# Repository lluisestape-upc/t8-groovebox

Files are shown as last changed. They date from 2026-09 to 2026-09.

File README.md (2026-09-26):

# T-8 Groovebox

A 16-step hardware groovebox built around an ESP32-WROOM-32, designed from scratch in KiCad 10. Two copper layers, 290 × 210 mm, DRC-clean and fabrication-ready.

> **Status: designed, not yet fabricated.**
> The layout passes DRC with **0 errors and 0 unconnected nets**, and the Gerber + drill package in [`fab/`](fab/) has been generated and checked. No board has been ordered yet, so nothing here has been measured on real hardware. Every performance figure in this README is a design intent, not a measurement.

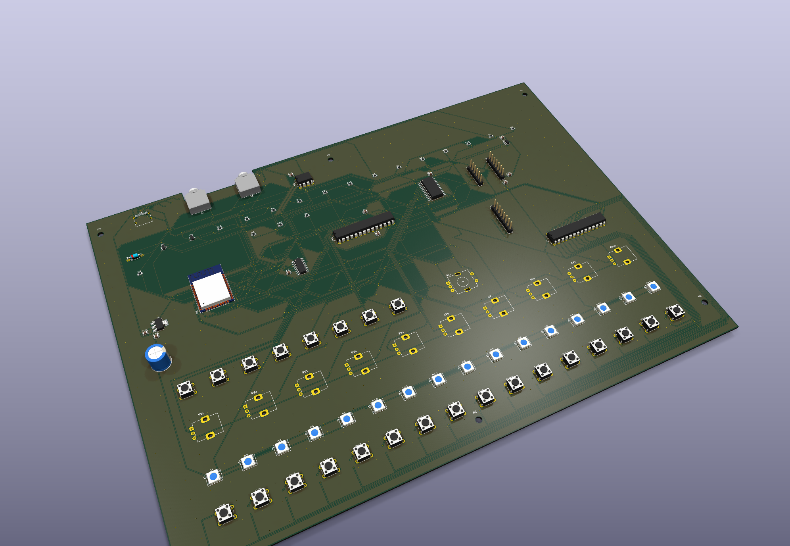
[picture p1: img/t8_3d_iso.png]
Isometric render of the assembled board


---

## What it is

A desktop groovebox in the spirit of the Roland T-8: sixteen step buttons with per-step RGB feedback, ten pots for live parameter control, a rotary encoder for menu navigation, a 2.4" colour display, MIDI in and out over TRS-A, and two independent audio outputs — a line-level I²S DAC and a class-D amplifier for a small onboard speaker. The whole thing is powered and programmed over a single USB-C connector.

The interesting part of this project is not the feature list, it is that the panel layout and most of the routing were **generated and repaired with the KiCad Python API** rather than drawn by hand. See [How the board was built](#how-the-board-was-built).

## Board at a glance

| | |
|---|---|
| Outline | 290.1 × 210.1 mm, with a 7 mm notch for the MIDI jacks |
| Copper layers | 2 (F.Cu / B.Cu), 1 oz |
| Footprints | 104 |
| Pads | 523 |
| Nets | 137 |
| Tracks | 2,570 segments |
| Vias | 1,148 (0.6 mm pad / 0.3 mm drill) |
| Copper zones | 1 GND plane, poured on both layers |
| Min track / clearance | 0.20 mm / 0.20 mm |
| Min drill | 0.30 mm |
| Min copper-to-edge | 0.50 mm |
| Mounting | 6 × M3 (3.2 mm) |
| DRC | 0 errors, 0 unconnected, 12 cosmetic silkscreen warnings |

### Renders

| Top | Bottom |
|---|---|
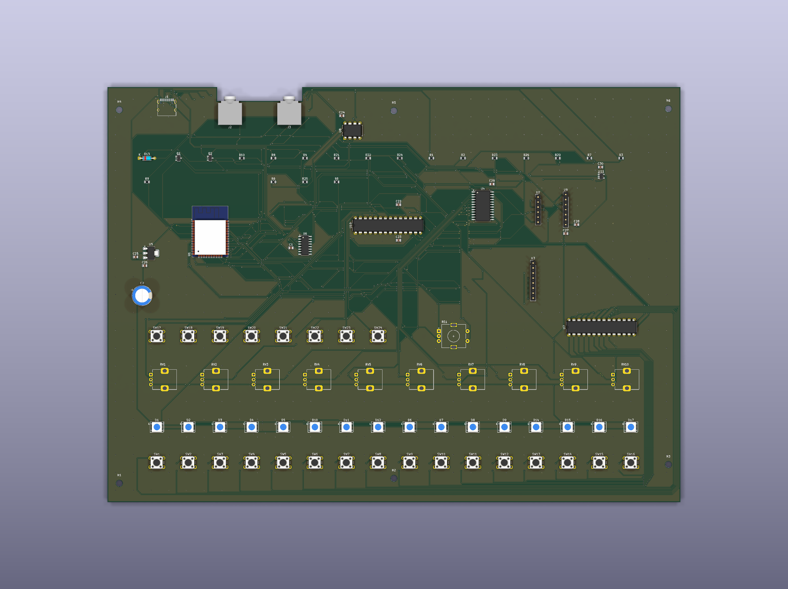
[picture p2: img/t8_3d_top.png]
Top
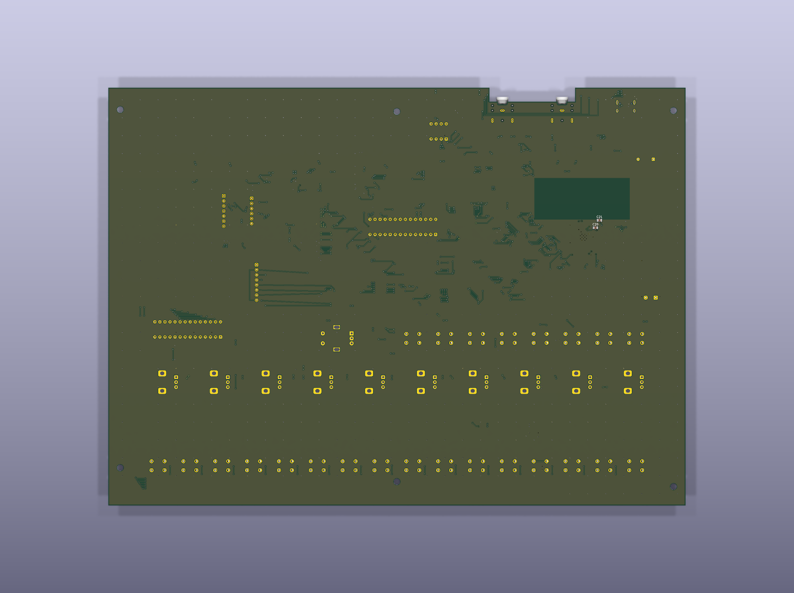
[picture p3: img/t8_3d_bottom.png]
Bottom
|  |  |

Vector fabrication views: [top](img/t8_2d_top.svg) · [bottom](img/t8_2d_bottom.svg)

PDFs: [schematic](T8Sequencer_esquematico.pdf) · [PCB](T8Sequencer_pcb.pdf)

---

## Signal chain

```mermaid
flowchart LR
  USB["USB-C J1"] --> UART["CH340C USB-UART"]
  USB --> LDO["AMS1117-3.3"]
  UART -->|UART0| ESP["ESP32-WROOM-32"]
  UART -.->|DTR / RTS via Q1, Q2| ESP
  LDO -->|3.3 V| ESP

  STEPS["16 step buttons"] --> EXP1["MCP23017 0x20"]
  FNKEYS["8 function buttons"] --> EXP2["MCP23017 0x21"]
  EXP1 -->|I2C| ESP
  EXP2 -->|I2C| ESP
  POTS["10 potentiometers"] --> MUX["CD74HC4067 16:1 mux"]
  MUX -->|ADC on GPIO34| ESP
  ENC["Rotary encoder + switch"] --> ESP

  ESP -->|GPIO16| LVL["74AHCT1G125 level shifter"]
  LVL -->|33 ohm series| LEDS["16x WS2812B"]
  ESP -->|SPI| DISP["ST7789 2.4in module"]
  ESP -->|I2S| DAC["I2S DAC header, line out"]
  ESP -->|I2S| AMP["MAX98357A module, speaker"]
  ESP -->|GPIO32| MOUT["MIDI OUT TRS-A, J3"]
  MIDIIN["MIDI IN TRS-A, J2"] --> OPTO["6N138 optocoupler"]
  OPTO -->|GPIO17| ESP
```

---

## Hardware

### Controls and indicators

| Qty | Part | Role |
|---|---|---|
| 16 | 6 mm tact switch | Step buttons (SW1–SW16) |
| 8 | 6 mm tact switch | PLAY, REC, SHIFT, PATT, TEMPO, CLEAR, F1, F2 (SW17–SW24) |
| 10 | Alps RK09K vertical | Parameter pots (RV1–RV10) |
| 1 | Alps EC11E + switch | Menu encoder |
| 16 | WS2812B (PLCC-4, 5×5 mm) | Per-step RGB feedback |
| 1 | ST7789 2.4" module | Display, on an 8-pin 2.54 mm header |

### Active devices

| Ref | Part | Package | Role |
|---|---|---|---|
| U1 | ESP32-WROOM-32 | module | Main MCU |
| U2 | — | 1×06 header | I²S DAC module, line out |
| U3 | ST7789 2.4" | 1×08 header | Display |
| U4 | CD74HC4067M | SOIC-24W | 16:1 analog mux for the pots |
| U5 | AMS1117-3.3 | SOT-223 | 3.3 V linear regulator |
| U6 | CH340C | SOIC-16 | USB to serial |
| U7 | MCP23017 | DIP-28 | I/O expander, step buttons (0x20) |
| U8 | 6N138 | DIP-8 | MIDI IN isolation |
| U9 | MAX98357A | 1×07 header | Class-D amp module, speaker out |
| U10 | MCP23017 | DIP-28 | I/O expander, function buttons (0x21) |
| U11 | 74AHCT1G125 | SOT-23-5 | 3.3 V to 5 V buffer for the LED data line |
| Q1, Q2 | NPN | SOT-23 | Auto-reset (DTR/RTS to EN/IO0) |

### Connectors

| Ref | Connector | Notes |
|---|---|---|
| J1 | USB-C receptacle, USB 2.0 14P | Power + programming, with 5.1 kΩ CC pulldowns |
| J2 | 3.5 mm TRS | MIDI IN, **TRS-A** (tip = DIN 5, ring = DIN 4) |
| J3 | 3.5 mm TRS | MIDI OUT, **TRS-A** |

Audio leaves the board through the connectors on the DAC and amplifier modules, not through board-mounted jacks.

---

## ESP32 pin map

| GPIO | Net | Function |
|---|---|---|
| 0 | `ESP_IO0` | Boot strap, driven by Q2 from RTS |
| 1 / 3 | `TX` / `RX` | UART0 to the CH340C |
| 2 | `DC` | Display data/command |
| 4 | `RES` | Display reset |
| 5 | `TFT_CS` | Display chip select |
| 12 | `MUX_S0` | Mux select bit 0 |
| 13 | `MUX_S1` | Mux select bit 1 |
| 14 | `MUX_S2` | Mux select bit 2 |
| 15 | `DISP_MOSI` | Display data |
| 16 | `LED_DATA` | WS2812B chain, via the 74AHCT1G125 |
| 17 | `MIDI_RX` | MIDI IN, from the 6N138 |
| 18 | `SCL` | I²C clock |
| 19 | `ENC_A` | Encoder channel A |
| 21 | `ENC_B` | Encoder channel B |
| 22 | `I2S_DIN` | I²S data out, shared by both audio devices |
| 23 | `SDA` | I²C data |
| 25 | `I2S_LCK` | I²S word clock |
| 26 | `I2S_BCK` | I²S bit clock |
| 27 | `MUX_S3` | Mux select bit 3 |
| 32 | `MIDI_TX` | MIDI OUT |
| 33 | `DISP_SCK` | Display clock |
| 34 | `MUX_SIG` | Pot mux output to ADC (input-only pin) |
| 35 | `ENC_SW` | Encoder push switch (input-only pin) |
| EN | `ESP_EN` | Reset, driven by Q1 from DTR |

`GPIO34` and `GPIO35` are input-only on the ESP32, which is exactly how they are used here. `GPIO12` is a boot strapping pin (MTDI); it is driven as a mux select with no external pull, so nothing holds it high at reset, but it is worth keeping in mind when writing the firmware.

## I²C and mux map

Both expanders share `SDA`/`SCL` with `RESET` tied to 3.3 V. Buttons pull to ground, so enable the internal pull-ups (`GPPU`).

| Device | Address | Port A | Port B |
|---|---|---|---|
| U7 | `0x20` | steps 1–8 | steps 9–16 |
| U10 | `0x21` | PLAY, REC, SHIFT, PATT, TEMPO, CLEAR, F1, F2 | free (8 spare inputs) |

The CD74HC4067 uses 10 of its 16 channels (`POT0`–`POT9`), selected by `MUX_S0..S3`, with the common pin read on `GPIO34`. Allow for RC settling between the channel switch and the ADC read.

The WS2812B chain is wired as a serpentine, not in reference order:

```
D1 → D2 → D3 → D4 → D5 → D10 → D11 → D12 → D6 → D7 → D8 → D9 → D14 → D15 → D16 → D17
```

Firmware has to map logical step *n* onto this physical order.

---

## Fabrication

[`fab/`](fab/) holds the complete package, also zipped as [`T8Sequencer_fab.zip`](T8Sequencer_fab.zip):

- 7 Gerbers — F.Cu, B.Cu, F.Mask, B.Mask, F.Silkscreen, B.Silkscreen, Edge.Cuts
- Excellon drill files, split PTH / NPTH
- `.gbrjob` job file

Settings the design was checked against:

| Setting | Value | Why |
|---|---|---|
| Layers | 2 | |
| Thickness | 1.6 mm | |
| Copper weight | 1 oz | 2 oz would raise the headroom of the 0.2 mm tracks from ≈0.74 A to ≈1.2 A, at higher cost |
| Min hole size | **0.3 mm** | 0.2 mm crosses into a much more expensive price tier |
| Min track / spacing | 0.2 mm / 0.2 mm | |
| Surface finish | HASL | |

The ESP32 thermal vias were deliberately enlarged from 0.2 mm to 0.3 mm drill (0.7 mm pad) purely to stay under the cheaper drill tier.

---

## Repository layout

```
T8Sequencer.kicad_pro          project
T8Sequencer.kicad_sch          schematic (single sheet)
T8Sequencer.kicad_pcb          layout
T8Sequencer.xml                netlist export
fp-lib-table                   project footprint libraries
sin_marco.kicad_wks            borderless worksheet, for clean plots
lib/Lluis.kicad_sym            custom symbols (module headers)
Lluis.pretty/                  custom footprints
LCD ST7789V.pretty/            the original FPC display footprint (superseded)
fab/                           Gerbers + drill
img/                           3D renders and 2D fabrication views
build_pcb.py                   board bring-up script
place_panel.py                 panel placement generator
scripts_arreglo/               the repair scripts, in the order they were run
```

### Opening the project

The schematic depends on the custom symbol library in `lib/Lluis.kicad_sym`, which is **not** registered by a project-level `sym-lib-table`. Add it once under *Preferences → Manage Symbol Libraries* with the nickname `Lluis`, or point an existing entry at the copy in `lib/`. The footprint libraries resolve automatically through `fp-lib-table`.

---

## How the board was built

The panel is a grid of 16 switches, 16 LEDs and 10 pots. Placing that by hand is tedious and error-prone, so the geometry is generated instead:

- **`place_panel.py`** computes the panel grid and writes footprint positions straight into the board.
- **`build_pcb.py`** handles board-level bring-up.
- **`scripts_arreglo/`** holds the repair passes in the order they were run — `fix1`–`fix9`, `fix11`, `fix12` for connectivity and geometry, `ruta`–`ruta4` for routing, `esq` for the schematic. Each one is a single, auditable change.

Two problems in there are worth reading if you ever script KiCad.

**Duplicate-numbered pads.** 73 pads in this design share a number with another pad in the same footprint — tact switches with two pads numbered 1 and two numbered 2, the USB-C shield with four `SH` pads, the ESP32 thermal pad split into eight. The netlist assigns a net to *one* of them, so the rest stay at net 0 and the copper never connects. Neither ERC nor the netlist reveals this. The fix walks every footprint, groups pads by number, and propagates the single non-zero net to its twins:

```python
byn = collections.defaultdict(list)
for p in f.Pads():
    byn[p.GetNumber()].append(p)
for num, ps in byn.items():
    nets = {p.GetNetCode() for p in ps if p.GetNetCode() != 0}
    if len(nets) == 1 and any(p.GetNetCode() == 0 for p in ps):
        net = B.FindNet(nets.pop())
        for p in ps:
            if p.GetNetCode() == 0:
                p.SetNet(net)
```

**`GetTracks()` is invalidated by `Remove()`.** Iterating the track list while deleting from it segfaults the interpreter. Collect first, delete afterwards:

```python
fuera = [t for t in B.GetTracks() if condicion(t)]
for t in fuera:
    B.Remove(t)
```

---

## Design notes and open risks

Written down plainly, because none of it has been measured yet.

**The 3.3 V regulator is the hot spot.** The AMS1117 drops 5 V to 3.3 V linearly, so it burns 1.7 V times whatever the rail draws:

| 3.3 V load | Dissipation | Rise over ambient (SOT-223) |
|---|---|---|
| 300 mA | 0.51 W | ≈40 °C |
| 500 mA | 0.85 W | ≈65 °C |
| 800 mA | 1.36 W | too much |

Quiescent operation is fine. With Wi-Fi transmitting (peaks around 500 mA) plus the display backlight, the package gets hot. This is the first thing to measure on a real board, and the obvious upgrade is a buck converter.

**The LED ring can outdraw a USB port.** 16 WS2812B at full white is roughly 960 mA on the 5 V rail, against the 500 mA a plain USB 2.0 port guarantees. Cap the brightness in firmware.

**Every track sits at the 0.2 mm minimum.** That is ≈0.74 A at 1 oz by IPC-2221 — adequate for the logic rails, with no margin on the 5 V LED rail. Widening the power tracks was attempted and produced 138+ clearance errors: the routing is dense enough that it needs manual rework, or 2 oz copper, or both.

**Three module pinouts are assumed, not verified.** The display (U3), the DAC (U2) and the amplifier (U9) are all 2.54 mm headers, and the pin order was taken from the common breakout variants. **Check the silkscreen on the parts you actually buy against the schematic before soldering.** The schematic carries a note to this effect on U9.

**12 silkscreen warnings remain.** Reference text on J2 and J3 overhangs the board edge near the MIDI notch. Cosmetic only, no effect on fabrication.

---

## Next steps

- [ ] Order the boards (1 oz, min hole 0.3 mm)
- [ ] Buy the 8-pin 2.4" ST7789 module and verify its pin order
- [ ] Verify the MAX98357A and I²S DAC module pinouts
- [ ] Prototype the firmware in simulation before the boards arrive
- [ ] Bring-up: power rails, regulator temperature, USB enumeration, auto-reset
- [ ] Characterise: line-out THD+N and noise floor, I²S end-to-end latency, MIDI TRS jitter, LED current against brightness
- [ ] Add silkscreen function labels for the pots and step buttons

---

## License

MIT — see [LICENSE](LICENSE).

Designed by [Lluís Estapé](https://github.com/lluisestape-upc). KiCad 10.0.1.

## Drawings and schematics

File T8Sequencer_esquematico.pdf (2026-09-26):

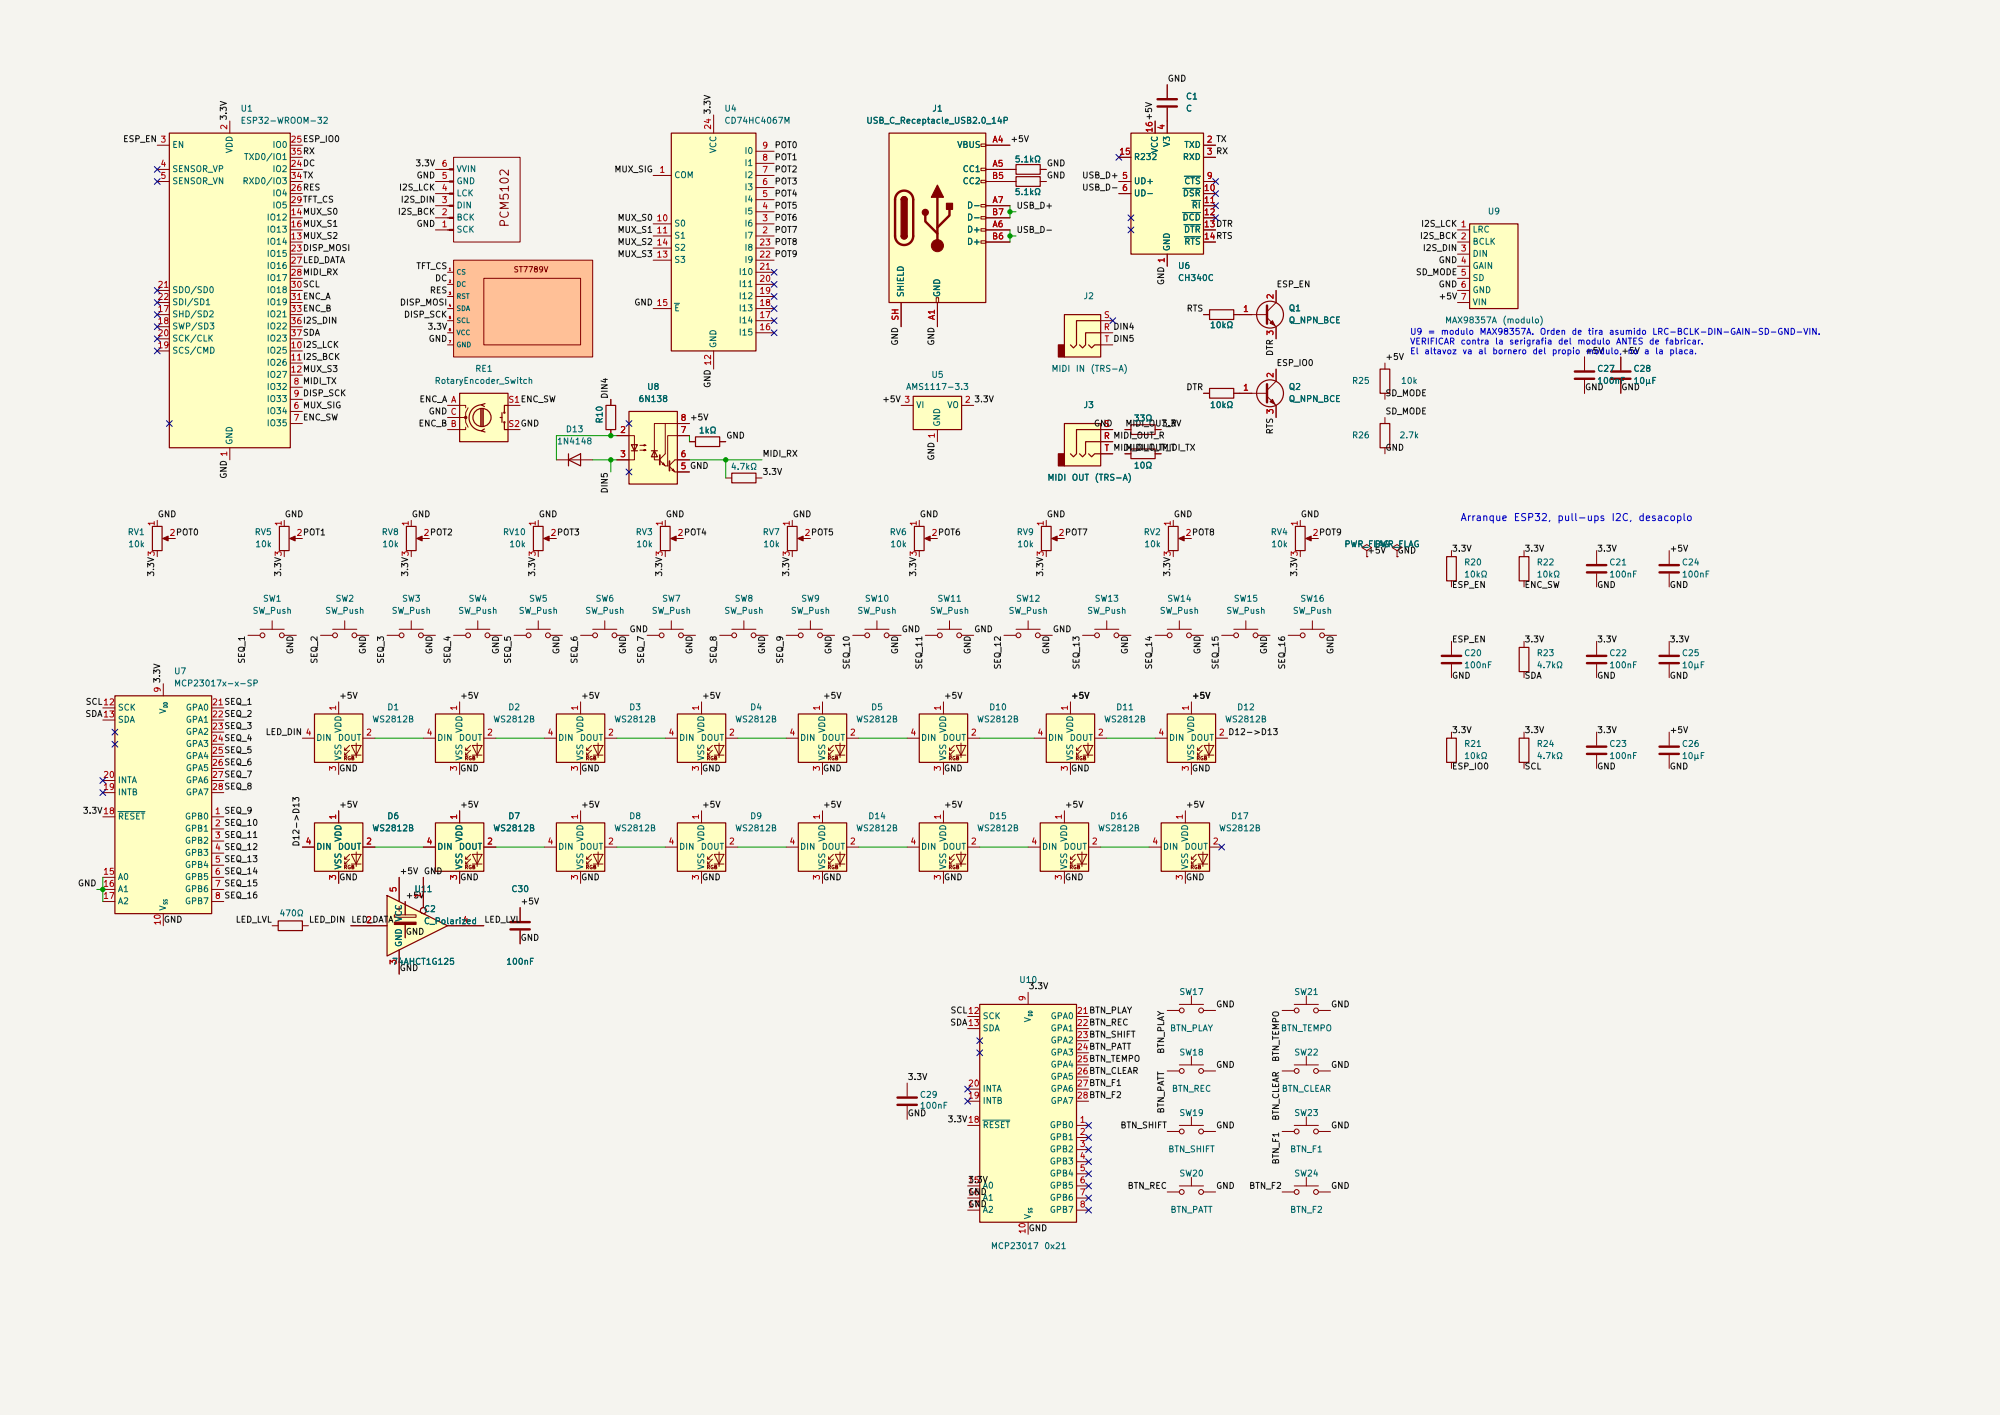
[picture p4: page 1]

4 UD+ 5 UD- 6 CTS 9 DSR 10 RI 11 DCD 12 DTR 13 RTS 14 R232 15 VCC 16 U6CH340C

4 UD+ 5 UD- 6 CTS 9 DSR 10 RI 11 DCD 12 DTR 13 RTS 14 R232 15 VCC 16 Q1Q_NPN_BCE 1

U9 = modulo MAX98357A. Orden de tira asumido LRC-BCLK-DIN-GAIN-SD-GND-VIN. VERIFICAR contra la serigrafia del modulo ANTES de fabricar. El altavoz va al bornero del propio modulo, no a la placa. PWR_FLAG

Arranque ESP32, pull-ups I2C, desacoplo

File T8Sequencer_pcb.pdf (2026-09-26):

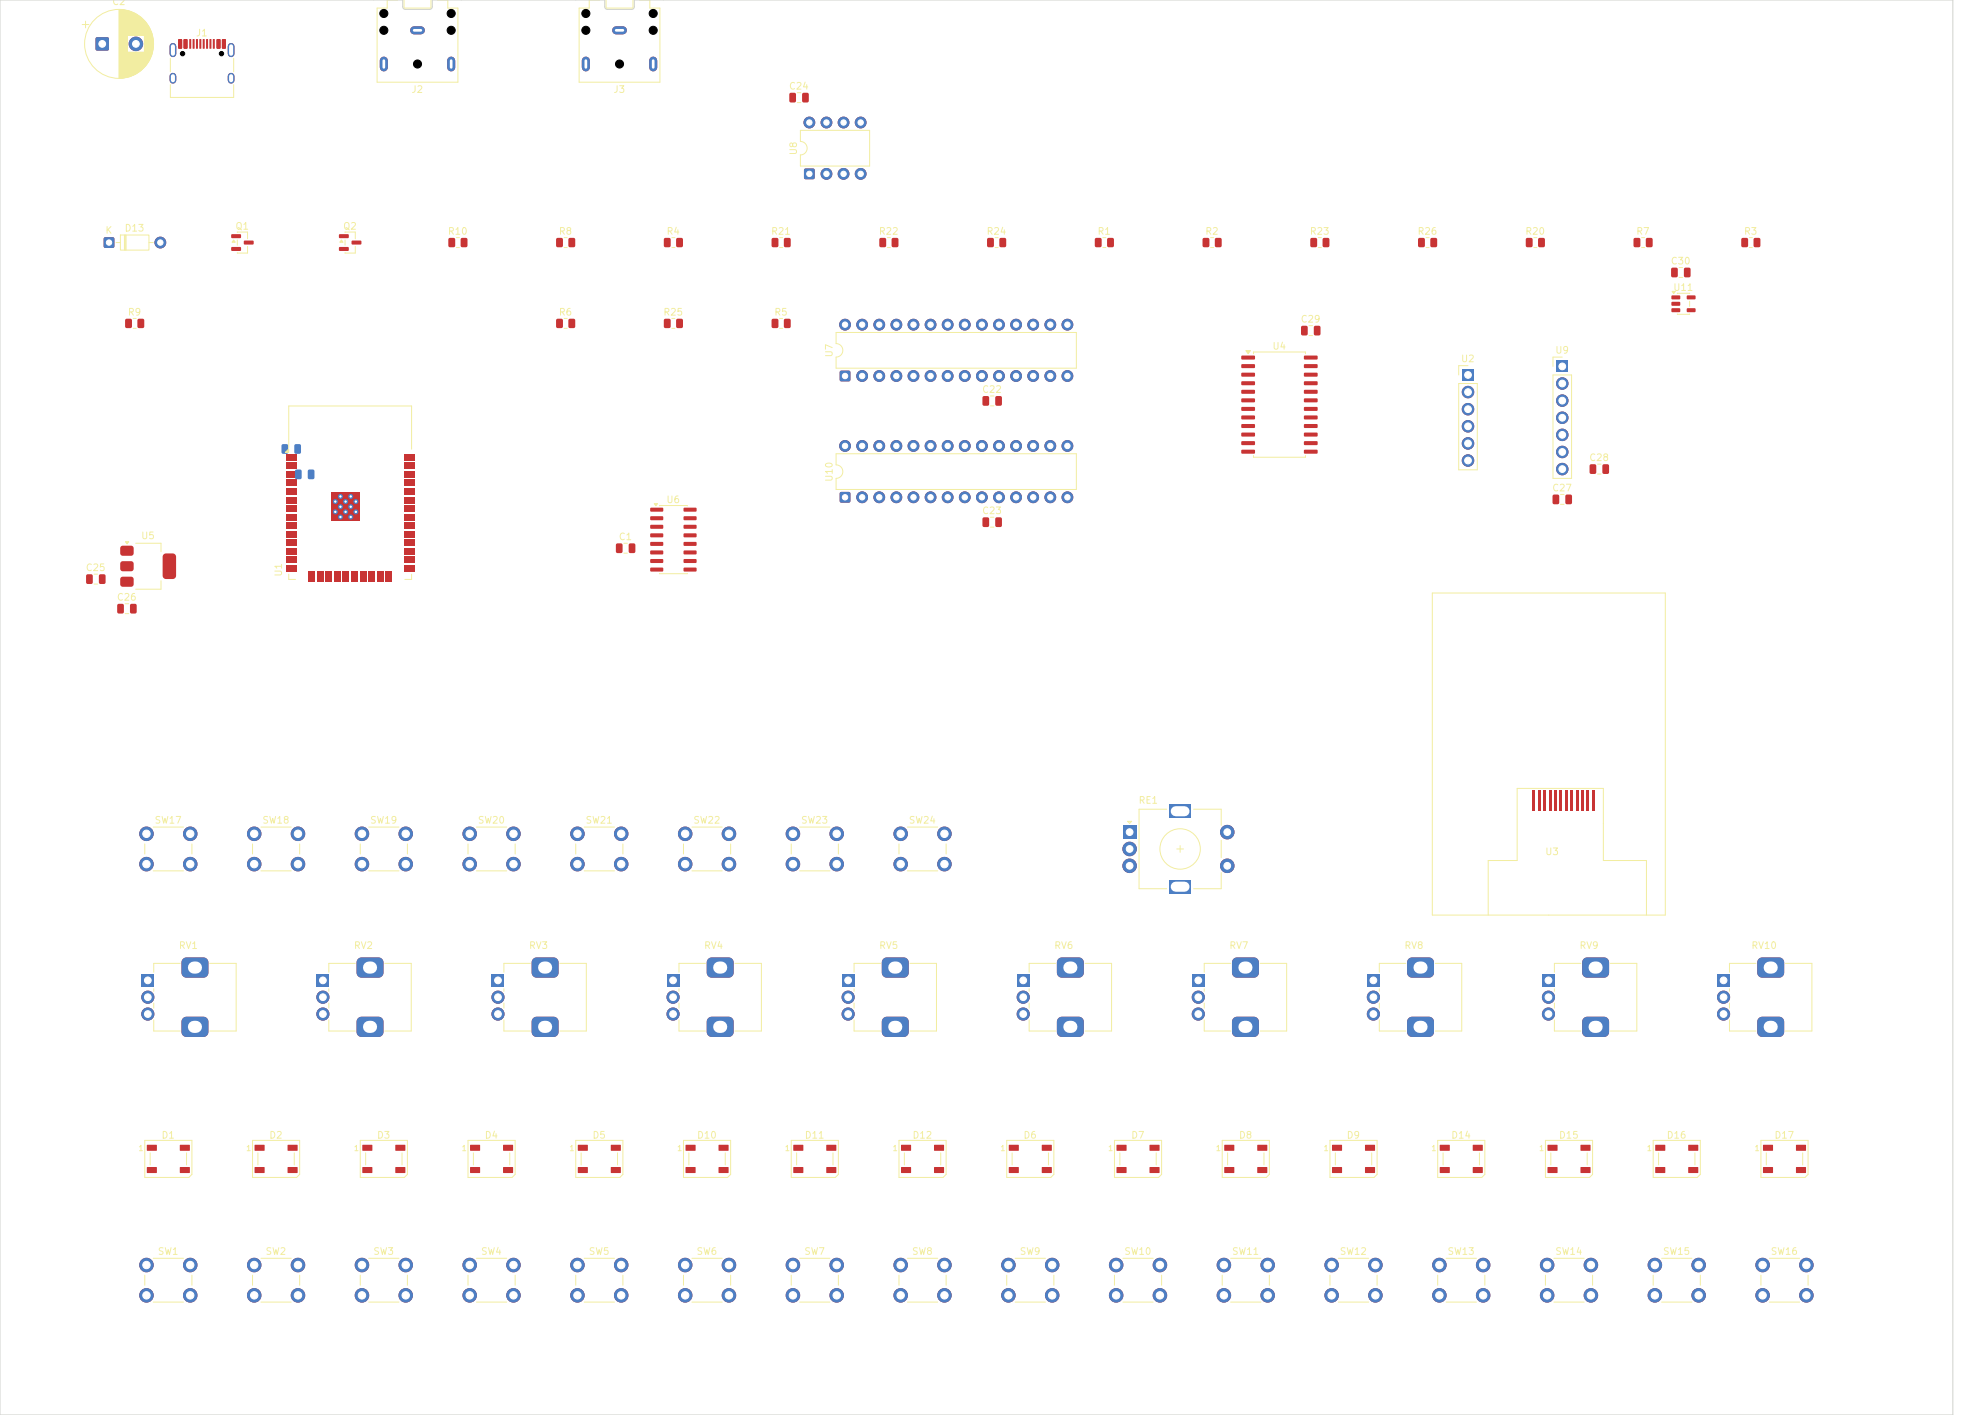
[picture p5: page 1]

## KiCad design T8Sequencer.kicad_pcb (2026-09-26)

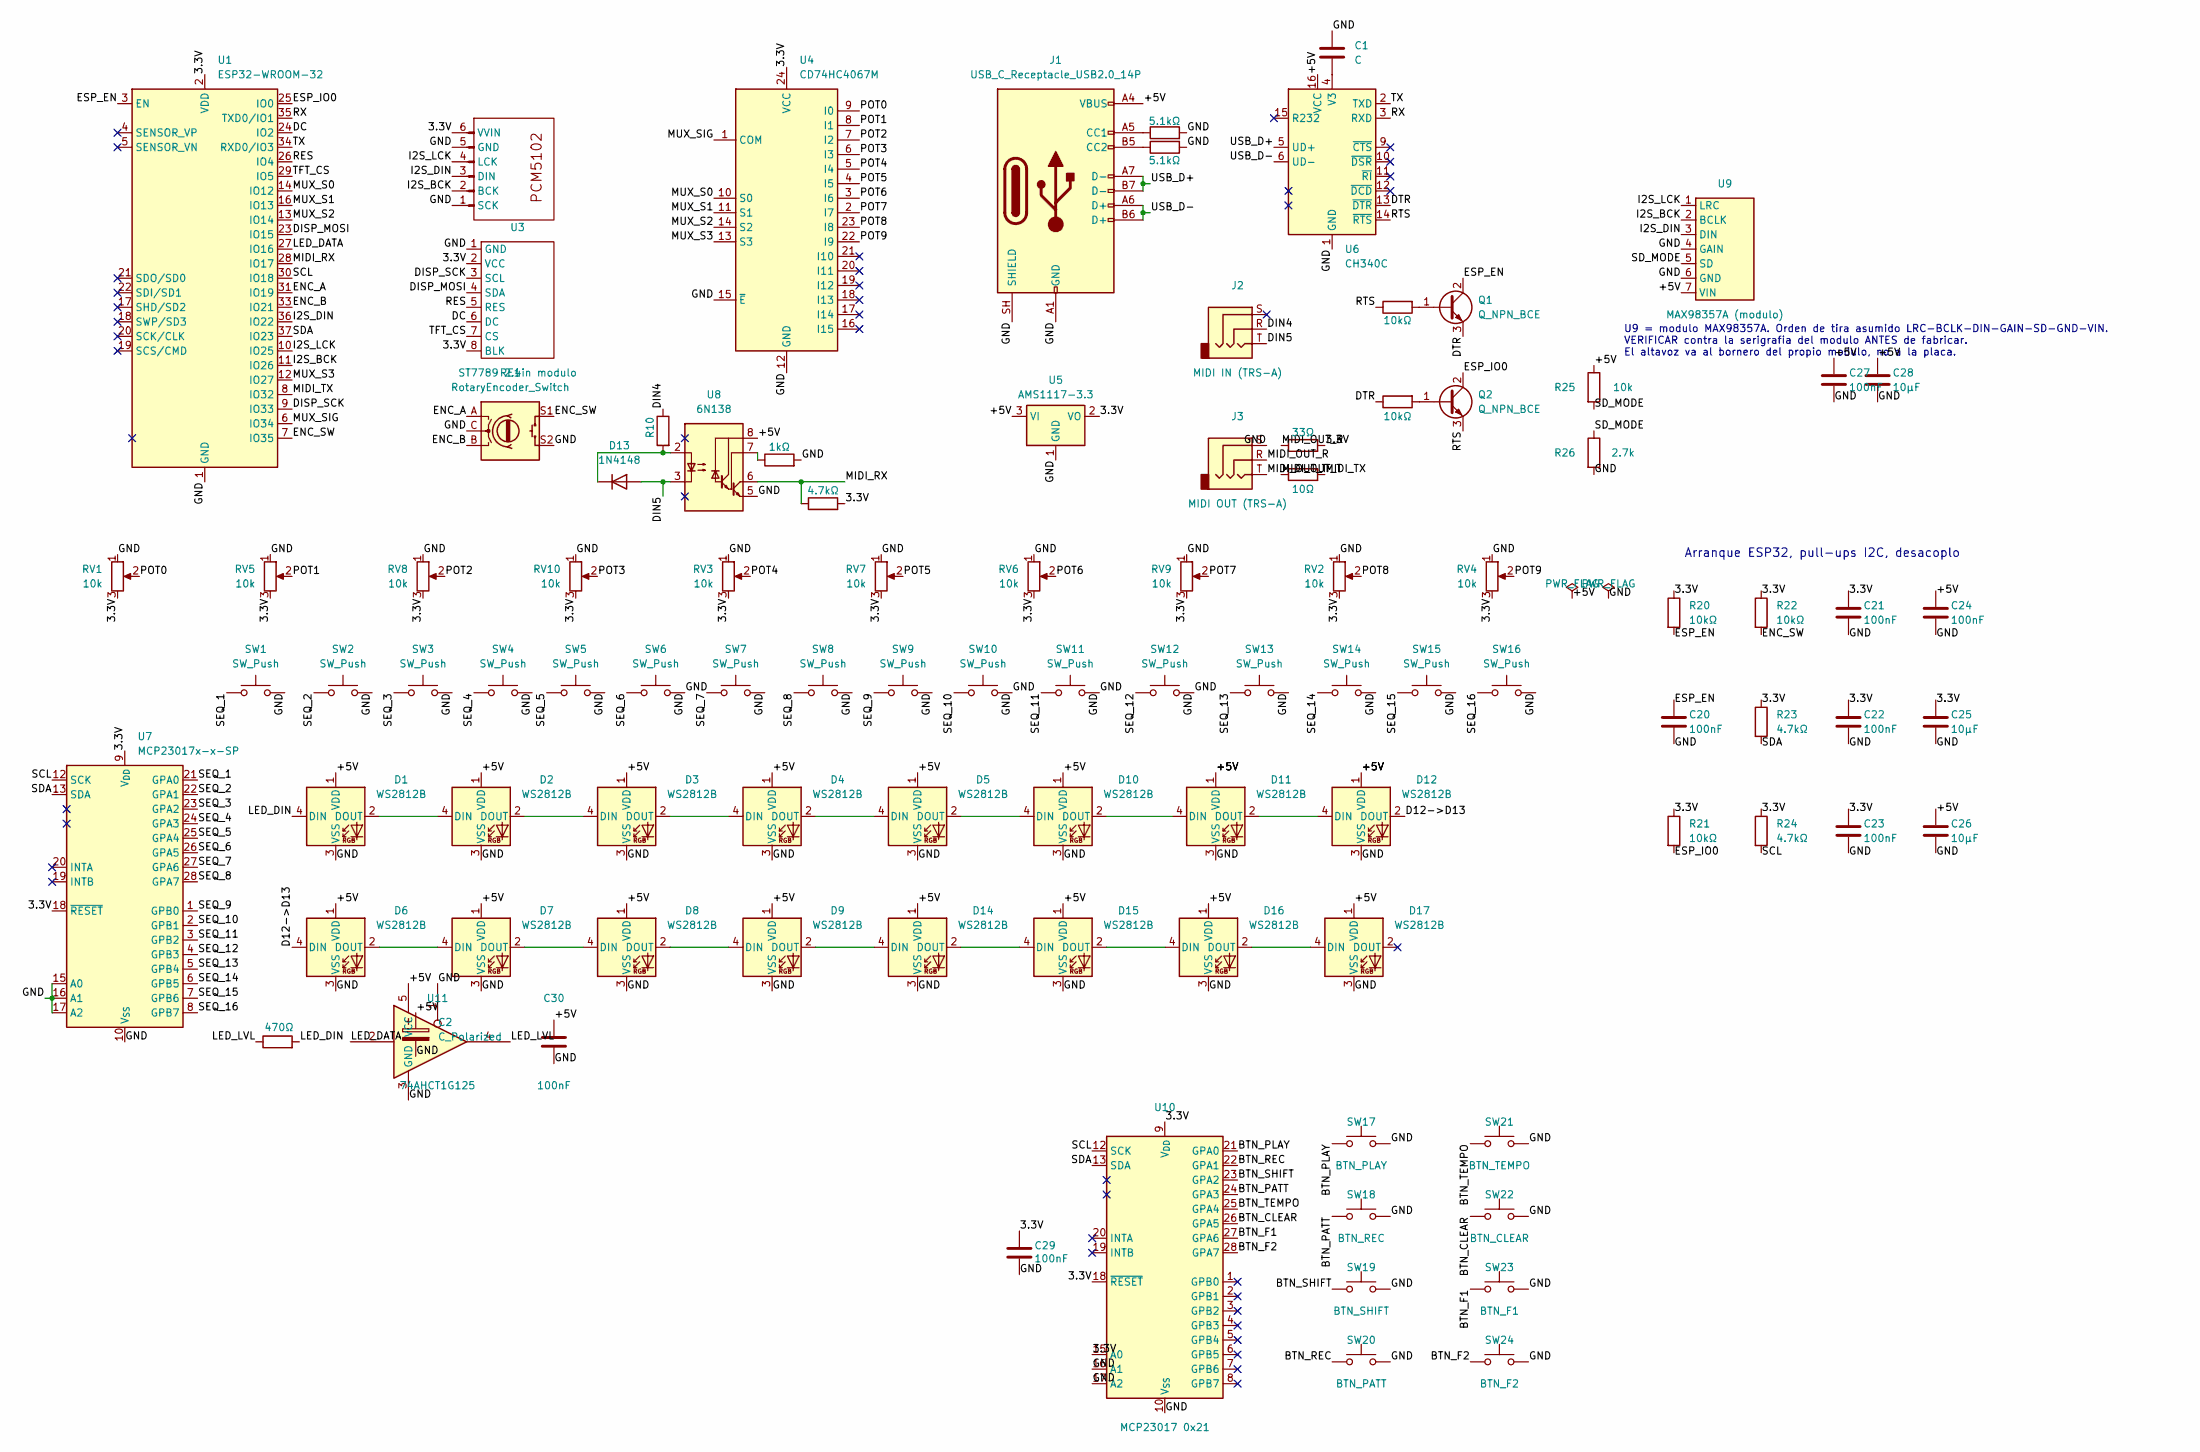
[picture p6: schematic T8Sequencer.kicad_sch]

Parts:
C1: C; C_0805_2012Metric
C2: C_Polarized; CP_Radial_D10.0mm_P5.00mm
C20, C21, C22, C23, C24, C27, C29, C30: 100nF; C_0805_2012Metric
C25, C26, C28: 10µF; C_0805_2012Metric
D1, D2, D3, D4, D5, D6, D7, D8, D9, D10, D11, D12, D14, D15, D16, D17: WS2812B; LED_WS2812B_PLCC4_5.0x5.0mm_P3.2mm
D13: 1N4148; D_DO-35_SOD27_P7.62mm_Horizontal
J1: USB_C_Receptacle_USB2.0_14P; USB_C_Receptacle_HRO_TYPE-C-31-M-12
J2: MIDI IN (TRS-A); Jack_3.5mm_CUI_SJ1-3523N_Horizontal
J3: MIDI OUT (TRS-A); Jack_3.5mm_CUI_SJ1-3523N_Horizontal
Q1, Q2: Q_NPN_BCE; SOT-23
R1, R2: 5.1kΩ; R_0805_2012Metric
R3, R4, R20, R21, R22: 10kΩ; R_0805_2012Metric
R5: 470Ω; R_0805_2012Metric
R6: 1kΩ; R_0805_2012Metric
R7, R23, R24: 4.7kΩ; R_0805_2012Metric
R8: 33Ω; R_0805_2012Metric
R9: 10Ω; R_0805_2012Metric
R10: 220; R_0805_2012Metric
R25: 10k; R_0805_2012Metric
R26: 2.7k; R_0805_2012Metric
RE1: RotaryEncoder_Switch; RotaryEncoder_Alps_EC11E-Switch_Vertical_H20mm
RV1, RV2, RV3, RV4, RV5, RV6, RV7, RV8, RV9, RV10: 10k; Potentiometer_Alps_RK09K_Single_Vertical
SW1, SW2, SW3, SW4, SW5, SW6, SW7, SW8, SW9, SW10, SW11, SW12, SW13, SW14, SW15, SW16: SW_Push; SW_PUSH_6mm
SW17: BTN_PLAY; SW_PUSH_6mm
SW18: BTN_REC; SW_PUSH_6mm
SW19: BTN_SHIFT; SW_PUSH_6mm
SW20: BTN_PATT; SW_PUSH_6mm
SW21: BTN_TEMPO; SW_PUSH_6mm
SW22: BTN_CLEAR; SW_PUSH_6mm
SW23: BTN_F1; SW_PUSH_6mm
SW24: BTN_F2; SW_PUSH_6mm
U1: ESP32-WROOM-32
U2: PinHeader_1x06_P2.54mm_Vertical
U3: ST7789 2.4in modulo; PinHeader_1x08_P2.54mm_Vertical
U4: CD74HC4067M; SOIC-24W_7.5x15.4mm_P1.27mm
U5: AMS1117-3.3; SOT-223-3_TabPin2
U6: CH340C; SOIC-16_3.9x9.9mm_P1.27mm
U7: MCP23017x-x-SP; DIP-28_W7.62mm
U8: 6N138; DIP-8_W7.62mm
U9: MAX98357A (modulo); PinHeader_1x07_P2.54mm_Vertical
U10: MCP23017 0x21; DIP-28_W7.62mm
U11: 74AHCT1G125; SOT-23-5

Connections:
/3.3V: C21.1, C22.1, C23.1, C25.1, C29.1, R7.2, R8.2, R20.1, R21.1, R22.1, R23.1, R24.1, RV1.3, RV2.3, RV3.3, RV4.3, RV5.3, RV6.3, RV7.3, RV8.3, RV9.3, RV10.3, U1.2 (VDD), U2.6 (VVIN), U3.2 (VCC), U3.8 (BLK), U4.24 (VCC), U5.2 (VO), U7.9 (V_{DD}), U7.18 (~RESET), U10.9 (V_{DD}), U10.15 (A0), U10.18 (~RESET)
/+5V: C2.1, C24.1, C26.1, C27.1, C28.1, C30.1, D1.1 (VDD), D2.1 (VDD), D3.1 (VDD), D4.1 (VDD), D5.1 (VDD), D6.1 (VDD), D7.1 (VDD), D8.1 (VDD), D9.1 (VDD), D10.1 (VDD), D11.1 (VDD), D12.1 (VDD), D14.1 (VDD), D15.1 (VDD), D16.1 (VDD), D17.1 (VDD), J1.A4 (VBUS), J1.A9 (VBUS), J1.B4 (VBUS), J1.B9 (VBUS), R25.1, U5.3 (VI), U6.16 (VCC), U8.8 (VCC), U9.7 (VIN), U11.5 (VCC)
/BTN_CLEAR: SW22.1, U10.26 (GPA5)
/BTN_F1: SW23.1, U10.27 (GPA6)
/BTN_F2: SW24.1, U10.28 (GPA7)
/BTN_PATT: SW18.1, U10.24 (GPA3)
/BTN_PLAY: SW17.1, U10.21 (GPA0)
/BTN_REC: SW20.1, U10.22 (GPA1)
/BTN_SHIFT: SW19.1, U10.23 (GPA2)
/BTN_TEMPO: SW21.1, U10.25 (GPA4)
/D12->D13: D6.4 (DIN), D12.2 (DOUT)
/DC: U1.24 (IO2), U3.6 (DC)
/DIN4: J2.R, R10.1
/DIN5: D13.2 (A), J2.T, U8.3 (C2)
/DISP_MOSI: U1.23 (IO15), U3.4 (SDA)
/DISP_SCK: U1.9 (IO33), U3.3 (SCL)
/DTR: Q1.3 (E), R4.1, U6.13 (~DTR)
/ENC_A: RE1.A, U1.31 (IO19)
/ENC_B: RE1.B, U1.33 (IO21)
/ENC_SW: R22.2, RE1.S1, U1.7 (IO35)
/ESP_EN: C20.1, Q1.2 (C), R20.2, U1.3 (EN)
/ESP_IO0: Q2.2 (C), R21.2, U1.25 (IO0)
/GND: C1.1, C2.2, C20.2, C21.2, C22.2, C23.2, C24.2, C25.2, C26.2, C27.2, C28.2, C29.2, C30.2, D1.3 (VSS), D2.3 (VSS), D3.3 (VSS), D4.3 (VSS), D5.3 (VSS), D6.3 (VSS), D7.3 (VSS), D8.3 (VSS), D9.3 (VSS), D10.3 (VSS), D11.3 (VSS), D12.3 (VSS), D14.3 (VSS), D15.3 (VSS), D16.3 (VSS), D17.3 (VSS), J1.A1 (GND), J1.A8, J1.A12 (GND), J1.B1 (GND), J1.B8, J1.B12 (GND), J1.SH (SHIELD), J3.S, R1.2, R2.2, R6.2, R26.2, RE1.C, RE1.S2, RV1.1, RV2.1, RV3.1, RV4.1, RV5.1, RV6.1, RV7.1, RV8.1, RV9.1, RV10.1, SW1.2, SW2.2, SW3.2, SW4.2, SW5.2, SW6.2, SW7.2, SW8.2, SW9.2, SW10.2, SW11.2, SW12.2, SW13.2, SW14.2, SW15.2, SW16.2, SW17.2, SW18.2, SW19.2, SW20.2, SW21.2, SW22.2, SW23.2, SW24.2, U1.1 (GND), U1.15 (GND), U1.38 (GND), U1.39 (GND), U2.1 (SCK), U2.5 (GND), U3.1 (GND), U4.12 (GND), U4.15 (~E), U5.1 (GND), U6.1 (GND), U7.10 (V_{SS}), U7.15 (A0), U7.16 (A1), U7.17 (A2), U8.5 (GND), U9.4 (GAIN), U9.6 (GND), U10.10 (V_{SS}), U10.16 (A1), U10.17 (A2), U11.1, U11.3 (GND)
/I2S_BCK: U1.11 (IO26), U2.2 (BCK), U9.2 (BCLK)
/I2S_DIN: U1.36 (IO22), U2.3 (DIN), U9.3 (DIN)
/I2S_LCK: U1.10 (IO25), U2.4 (LCK), U9.1 (LRC)
/LED_DATA: U1.27 (IO16), U11.2
/LED_DIN: D1.4 (DIN), R5.2
/LED_LVL: R5.1, U11.4
/MIDI_OUT_R: J3.R, R8.1
/MIDI_OUT_T: J3.T, R9.1
/MIDI_RX: R7.1, U1.28 (IO17), U8.6 (VO2)
/MIDI_TX: R9.2, U1.8 (IO32)
/MUX_S0: U1.14 (IO12), U4.10 (S0)
/MUX_S1: U1.16 (IO13), U4.11 (S1)
/MUX_S2: U1.13 (IO14), U4.14 (S2)
/MUX_S3: U1.12 (IO27), U4.13 (S3)
/MUX_SIG: U1.6 (IO34), U4.1 (COM)
/POT0: RV1.2, U4.9 (I0)
/POT1: RV5.2, U4.8 (I1)
/POT2: RV8.2, U4.7 (I2)
/POT3: RV10.2, U4.6 (I3)
/POT4: RV3.2, U4.5 (I4)
/POT5: RV7.2, U4.4 (I5)
/POT6: RV6.2, U4.3 (I6)
/POT7: RV9.2, U4.2 (I7)
/POT8: RV2.2, U4.23 (I8)
/POT9: RV4.2, U4.22 (I9)
/RES: U1.26 (IO4), U3.5 (RES)
/RTS: Q2.3 (E), R3.1, U6.14 (~RTS)
/RX: U1.35 (TXD0/IO1), U6.3 (RXD)
/SCL: R24.2, U1.30 (IO18), U7.12 (SCK), U10.12 (SCK)
/SDA: R23.2, U1.37 (IO23), U7.13 (SDA), U10.13 (SDA)
/SD_MODE: R25.2, R26.1, U9.5 (SD)
/SEQ_1: SW1.1, U7.21 (GPA0)
/SEQ_2: SW2.1, U7.22 (GPA1)
/SEQ_3: SW3.1, U7.23 (GPA2)
/SEQ_4: SW4.1, U7.24 (GPA3)
/SEQ_5: SW5.1, U7.25 (GPA4)
/SEQ_6: SW6.1, U7.26 (GPA5)
/SEQ_7: SW7.1, U7.27 (GPA6)
/SEQ_8: SW8.1, U7.28 (GPA7)
/SEQ_9: SW9.1, U7.1 (GPB0)
/SEQ_10: SW10.1, U7.2 (GPB1)
/SEQ_11: SW11.1, U7.3 (GPB2)
/SEQ_12: SW12.1, U7.4 (GPB3)
/SEQ_13: SW13.1, U7.5 (GPB4)
/SEQ_14: SW14.1, U7.6 (GPB5)
/SEQ_15: SW15.1, U7.7 (GPB6)
/SEQ_16: SW16.1, U7.8 (GPB7)
/TFT_CS: U1.29 (IO5), U3.7 (CS)
/TX: U1.34 (RXD0/IO3), U6.2 (TXD)
/USB_D+: J1.A7 (D-), J1.B7 (D-), U6.5 (UD+)
/USB_D-: J1.A6 (D+), J1.B6 (D+), U6.6 (UD-)
unnamed: D1.2 (DOUT), D2.4 (DIN)
unnamed: D2.2 (DOUT), D3.4 (DIN)
unnamed: D3.2 (DOUT), D4.4 (DIN)
unnamed: D4.2 (DOUT), D5.4 (DIN)
unnamed: D6.2 (DOUT), D7.4 (DIN)
unnamed: D7.2 (DOUT), D8.4 (DIN)
unnamed: D8.2 (DOUT), D9.4 (DIN)
unnamed: D5.2 (DOUT), D10.4 (DIN)
unnamed: D10.2 (DOUT), D11.4 (DIN)
unnamed: D11.2 (DOUT), D12.4 (DIN)
unnamed: D13.1 (K), R10.2, U8.2 (C1)
unnamed: D9.2 (DOUT), D14.4 (DIN)
unnamed: D14.2 (DOUT), D15.4 (DIN)
unnamed: D15.2 (DOUT), D16.4 (DIN)
unnamed: D16.2 (DOUT), D17.4 (DIN)
unnamed: J1.A5 (CC1), R1.1
unnamed: J1.B5 (CC2), R2.1
unnamed: Q1.1 (B), R3.2
unnamed: Q2.1 (B), R4.2
unnamed: C1.2, U6.4 (V3)
unnamed: R6.1, U8.7 (VO1)

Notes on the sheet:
Arranque ESP32, pull-ups I2C, desacoplo
U9 = modulo MAX98357A. Orden de tira asumido LRC-BCLK-DIN-GAIN-SD-GND-VIN. VERIFICAR contra la serigrafia del modulo ANTES de fabricar. El altavoz va al bornero del propio modulo, no a la placa.

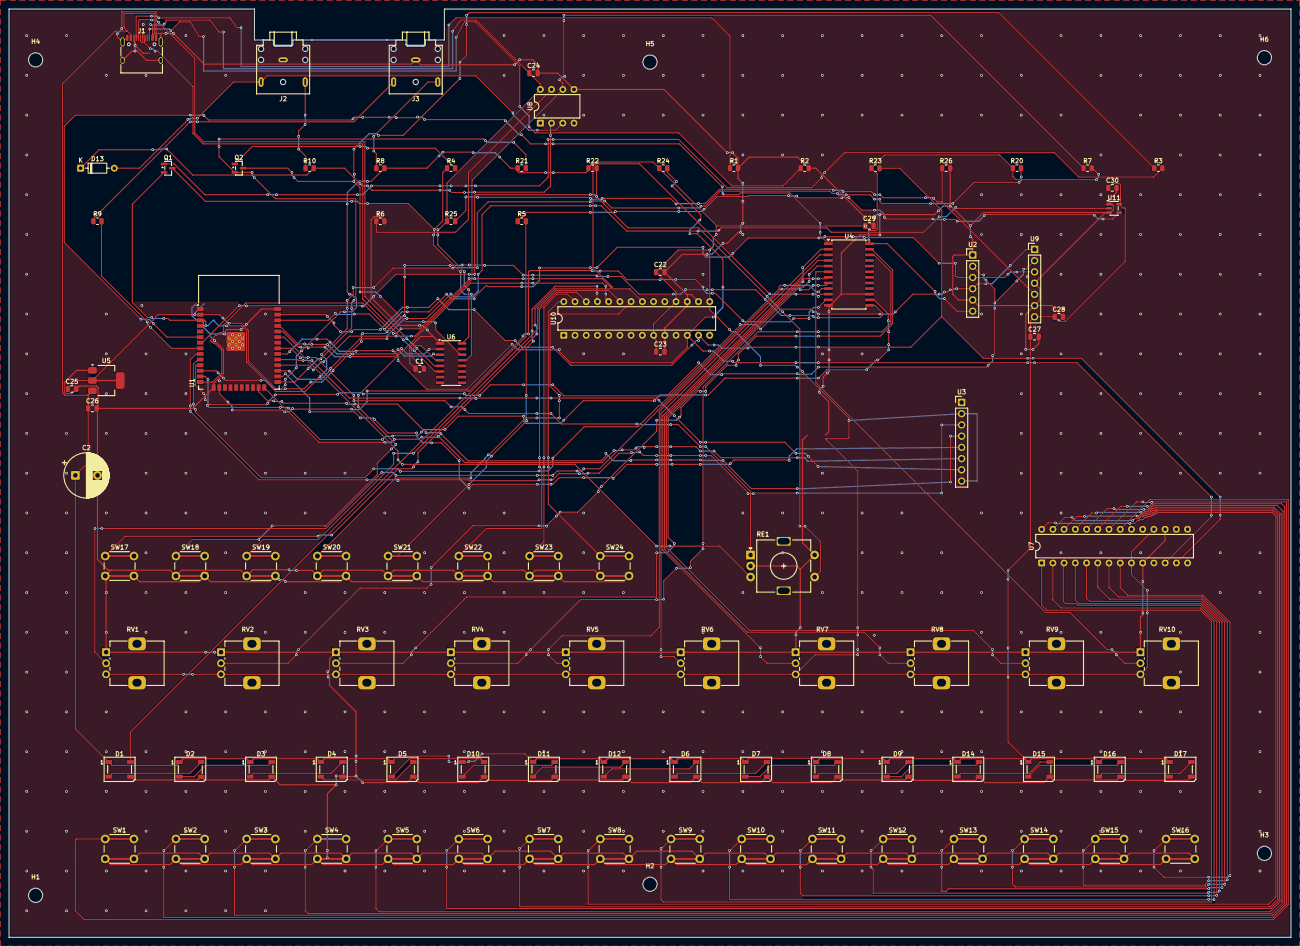
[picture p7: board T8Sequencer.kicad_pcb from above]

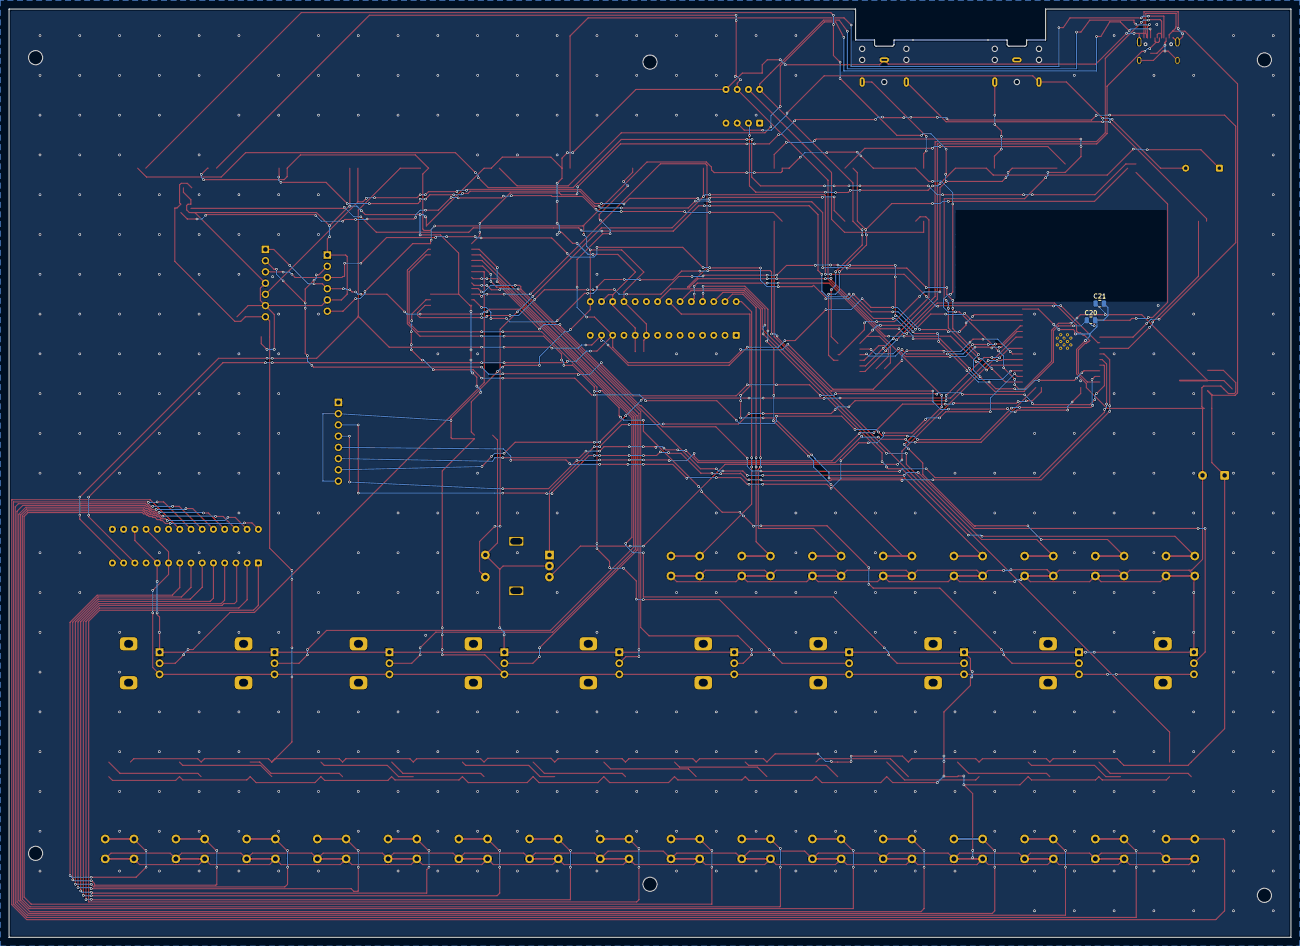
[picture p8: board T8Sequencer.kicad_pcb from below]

Board: 2 copper layers, 290.0 x 210.0 mm, 104 parts (2 on the bottom side), 95 nets.

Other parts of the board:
H1, H2, H3, H4, H5, H6: MountingHole_3.2mm_M3

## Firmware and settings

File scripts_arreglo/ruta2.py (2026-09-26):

# -*- coding: utf-8 -*-
import pcbnew
B = pcbnew.LoadBoard("T8Sequencer.kicad_pcb")
FM, TM = pcbnew.FromMM, pcbnew.ToMM
def V(x,y): return pcbnew.VECTOR2I(FM(x), FM(y))
F, Bo = pcbnew.F_Cu, pcbnew.B_Cu
def cerca(p,x,y,tol=0.03): return abs(TM(p.x)-x)<tol and abs(TM(p.y)-y)<tol

# --- borrar el intento anterior y los ramales muertos del display -----------
BORRA = [("/DISP_SCK",191.35,109.50,215.50,94.08),
         ("/DISP_MOSI",184.50,98.80,191.00,105.30),
         ("/DISP_MOSI",191.00,105.30,191.00,109.00),
         ("/DISP_SCK",191.60,104.67,184.93,98.00),
         ("/DISP_SCK",191.60,109.50,191.60,104.67)]
fuera=[]
for t in B.GetTracks():
    if t.GetClass()=="PCB_VIA":
        if t.GetNetname()=="/DISP_SCK" and cerca(t.GetPosition(),191.35,109.50): fuera.append(t)
        continue
    for n,x1,y1,x2,y2 in BORRA:
        if t.GetNetname()!=n: continue
        a,b=t.GetStart(),t.GetEnd()
        if (cerca(a,x1,y1) and cerca(b,x2,y2)) or (cerca(a,x2,y2) and cerca(b,x1,y1)):
            fuera.append(t); break
print("elementos retirados (intento previo + ramales muertos):", len(fuera))
for t in fuera: B.Remove(t)

# --- rutado definitivo --------------------------------------------------------
def trk(x1,y1,x2,y2,layer,net,w=0.2):
    t=pcbnew.PCB_TRACK(B); t.SetStart(V(x1,y1)); t.SetEnd(V(x2,y2))
    t.SetLayer(layer); t.SetWidth(FM(w)); t.SetNet(B.FindNet(net)); B.Add(t)
def via(x,y,net):
    v=pcbnew.PCB_VIA(B); v.SetPosition(V(x,y)); v.SetViaType(pcbnew.VIATYPE_THROUGH)
    v.SetLayerPair(F,Bo); v.SetDrill(FM(0.3))
    try: v.SetWidth(FM(0.6))
    except TypeError: v.SetWidth(F,FM(0.6))
    v.SetNet(B.FindNet(net)); B.Add(v)

# RES y DC: recta por la cara inferior, no se cruzan con nadie
trk(180.10, 99.50, 215.50, 99.16, Bo, "/RES");   print("  /RES      -> pin 5, recta por B.Cu")
trk(180.10,101.50, 215.50,101.70, Bo, "/DC");    print("  /DC       -> pin 6, recta por B.Cu")

# CS: salta por arriba a la cara superior para pasar por debajo de DC
trk(180.84,101.18, 182.50,103.00, F,  "/TFT_CS"); via(182.50,103.00,"/TFT_CS")
trk(182.50,103.00, 215.50,104.24, Bo, "/TFT_CS"); print("  /TFT_CS   -> pin 7, esquiva a DC")

# MOSI: sale del bus de y=109, cruza por B.Cu y sube por F.Cu en x=213
trk(191.00,109.00, 193.00,107.00, F,  "/DISP_MOSI"); via(193.00,107.00,"/DISP_MOSI")
trk(193.00,107.00, 213.00,107.00, Bo, "/DISP_MOSI"); via(213.00,107.00,"/DISP_MOSI")
trk(213.00,107.00, 213.00, 96.62, F,  "/DISP_MOSI"); via(213.00, 96.62,"/DISP_MOSI")
trk(213.00, 96.62, 215.50, 96.62, Bo, "/DISP_MOSI"); print("  /DISP_MOSI-> pin 4, sube por x=213")

# SCK: igual pero subiendo por x=211
trk(191.60,109.50, 194.50,109.50, F,  "/DISP_SCK"); via(194.50,109.50,"/DISP_SCK")
trk(194.50,109.50, 211.00,109.50, Bo, "/DISP_SCK"); via(211.00,109.50,"/DISP_SCK")
trk(211.00,109.50, 211.00, 94.08, F,  "/DISP_SCK"); via(211.00, 94.08,"/DISP_SCK")
trk(211.00, 94.08, 215.50, 94.08, Bo, "/DISP_SCK"); print("  /DISP_SCK -> pin 3, sube por x=211")

pcbnew.ZONE_FILLER(B).Fill(B.Zones())
B.Save("T8Sequencer.kicad_pcb")
print("guardado")
